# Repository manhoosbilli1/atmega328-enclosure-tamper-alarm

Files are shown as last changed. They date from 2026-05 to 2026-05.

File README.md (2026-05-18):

# Alarming_AC_Enclosure

ATmega328-based AC enclosure tamper/intrusion alarm with PowerPath, voltage monitoring, and dual switching converters

## At a Glance

- **Status**: In progress
- **Board size**: 100 x 60 mm
- **Layers**: 2
- **Components**: 98
- **Key ICs**:
  - U1: 74LVC1G00
  - U2: ATmega328-A
  - U3: LM5158QRTERQ1
  - U4: TPS62933DRLR
  - U5: LTC4412ES6#TRPBF
  - U6: LTC2960CTS8-1#TRMPBF

## Schematic

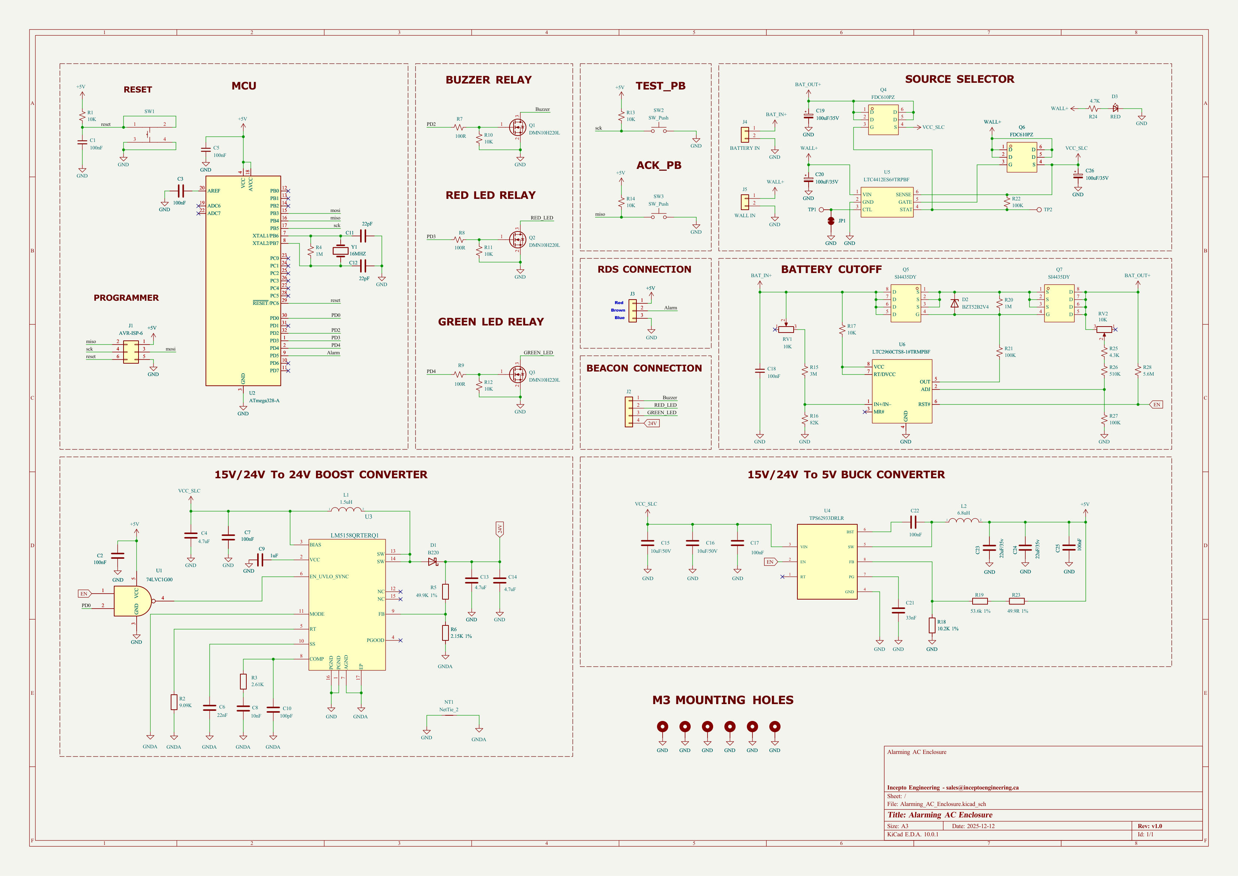
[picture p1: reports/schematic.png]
Schematic


Full PDF: [reports/schematic.pdf](reports/schematic.pdf)

## Component Roles

- **ATmega328-A** - main MCU; reads tamper switches, manages alarm state, drives outputs
- **LTC4412ES6** - low-loss ideal-diode / PowerPath controller; manages source switching between mains-derived rail and backup battery seamlessly
- **LTC2960CTS8-1** - precision voltage monitor / supervisor; trips the alarm if either supply rail dips out of spec
- **LM5158QRTERQ1** - automotive-grade boost converter (LM5158-Q1); steps up battery voltage to feed the alarm load when on backup
- **TPS62933PDRLR** - low-Iq buck converter for the MCU rail (long battery standby)
- **DMN10H220L** - N-channel MOSFET for high-side / load switching
- **FDC610PZ** - P-channel MOSFET (complementary side for OR-ing / load isolation)
- **B220** - Schottky diode for reverse / OR-ing logic
- **BZT52Bxx** - zener diode for clamp / reference
- **1TS005F-2500-5001** - tactile reset/test switch
- **74LVC1G00** - single 2-input NAND gate for combining tamper inputs / debounce logic
- **Crystal** for ATmega clock

> Designed as a self-powered enclosure tamper alarm: stays armed on AC, falls back to battery when AC is cut, alerts when either supply rail is out of spec.

## PCB

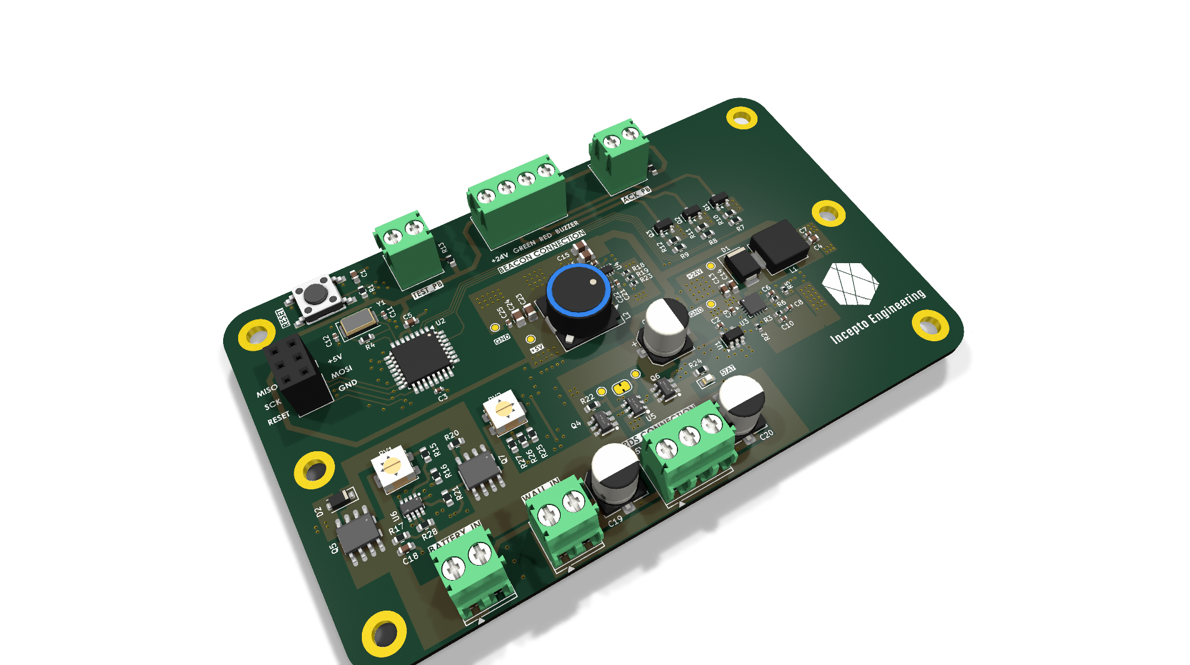
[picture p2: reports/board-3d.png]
3D top


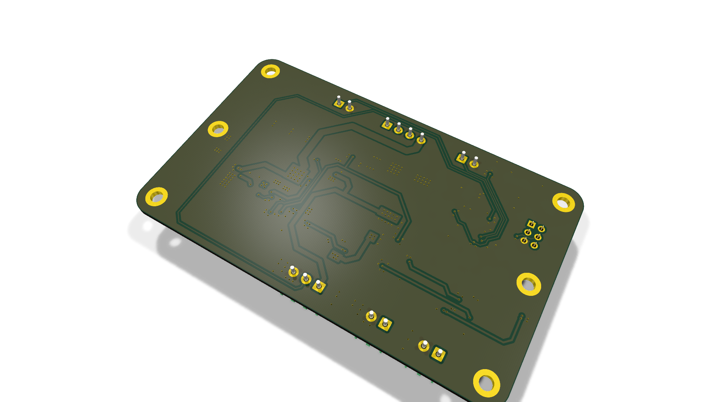
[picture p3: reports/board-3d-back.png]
3D bottom


**Top copper**

PCB top

**Bottom copper**

PCB bottom

## Bill of Materials

| Refs | Value | Footprint | Qty | MPN | LCSC |
|---|---|---|----:|-----|---|
| C1,C5,C18 | 100nF | Capacitor_SMD:C_0603_1608Metric | 3 |  |  |
| C2,C3,C7,C17,C22,C25 | 100nF | Capacitor_SMD:C_0402_1005Metric | 6 |  |  |
| C4,C13,C14 | 4.7uF | Capacitor_SMD:C_0603_1608Metric | 3 |  |  |
| C6 | 22nF | Capacitor_SMD:C_0402_1005Metric | 1 |  |  |
| C8 | 10nF | Capacitor_SMD:C_0402_1005Metric | 1 |  |  |
| C9 | 1uF | Capacitor_SMD:C_0402_1005Metric | 1 |  |  |
| C10 | 100pF | Capacitor_SMD:C_0402_1005Metric | 1 |  |  |
| C11,C12 | 22pF | Capacitor_SMD:C_0402_1005Metric | 2 |  |  |
| C15,C16 | 10uF/50V | Capacitor_SMD:C_0805_2012Metric | 2 |  |  |
| C19,C20,C26 | 100uF/35V | Capacitor_SMD:CP_Elec_6.3x7.7 | 3 |  |  |
| C21 | 33nF | Capacitor_SMD:C_0402_1005Metric | 1 |  |  |
| C23,C24 | 22uF/35v | Capacitor_SMD:C_0805_2012Metric | 2 |  |  |
| D1 | B220 | Diode_SMD:D_SMB | 1 |  |  |
| D2 | BZT52B2V4 | Diode_SMD:D_SOD-123F | 1 |  |  |
| D3 | RED | LED_SMD:LED_0603_1608Metric | 1 |  |  |
| J1 | AVR-ISP-6 | Connector_PinSocket_2.54mm:PinSocket_2x03_P2.54mm_Vertical | 1 |  |  |
| J2 | Conn_01x04 | TerminalBlock_Phoenix:TerminalBlock_Phoenix_PT-1,5-4-3.5-H_1x04_P3.50mm_Horizontal | 1 |  |  |
| J3 | Conn_01x03 | TerminalBlock_Phoenix:TerminalBlock_Phoenix_PT-1,5-3-3.5-H_1x03_P3.50mm_Horizontal | 1 |  |  |
| J4 | BATTERY IN | TerminalBlock_Phoenix:TerminalBlock_Phoenix_PT-1,5-2-3.5-H_1x02_P3.50mm_Horizontal | 1 |  |  |
| J5 | WALL IN | TerminalBlock_Phoenix:TerminalBlock_Phoenix_PT-1,5-2-3.5-H_1x02_P3.50mm_Horizontal | 1 |  |  |
| L1 | 1.5uH | Inductor_SMD:L_Sunlord_MWSA0603S | 1 |  |  |
| L2 | 6.8uH | Inductor_SMD:L_TDK_SLF10165 | 1 |  |  |
| Q1-Q3 | DMN10H220L | Package_TO_SOT_SMD:SOT-23 | 3 |  |  |
| Q4,Q6 | FDC610PZ | FDC610PZ:SOT-23-6_L2.9-W1.6-P0.95-LS2.8-BR | 2 |  |  |
| Q5,Q7 | SI4435DY | SI4435DY:SOP-8_L4.9-W3.9-P1.27-LS6.0-BL | 2 |  |  |
| R1,R10-R14,R17 | 10K | Resistor_SMD:R_0603_1608Metric | 7 |  |  |
| R2 | 9.09K | Resistor_SMD:R_0402_1005Metric | 1 |  |  |
| R3 | 2.61K | Resistor_SMD:R_0402_1005Metric | 1 |  |  |
| R4,R20 | 1M | Resistor_SMD:R_0603_1608Metric | 2 |  |  |
| R5 | 49.9K 1% | Resistor_SMD:R_0402_1005Metric | 1 |  |  |
| R6 | 2.15K 1% | Resistor_SMD:R_0402_1005Metric | 1 |  |  |
| R7-R9 | 100R | Resistor_SMD:R_0603_1608Metric | 3 |  |  |
| R15 | 3M | Resistor_SMD:R_0603_1608Metric | 1 |  |  |
| R16 | 82K | Resistor_SMD:R_0603_1608Metric | 1 |  |  |
| R18 | 10.2K 1% | Resistor_SMD:R_0402_1005Metric | 1 |  |  |
| R19 | 53.6k 1% | Resistor_SMD:R_0402_1005Metric | 1 |  |  |
| R21,R22,R27 | 100K | Resistor_SMD:R_0603_1608Metric | 3 |  |  |
| R23 | 49.9R 1% | Resistor_SMD:R_0402_1005Metric | 1 |  |  |
| R24 | 4.7K | Resistor_SMD:R_0603_1608Metric | 1 |  |  |
| R25 | 4.3K | Resistor_SMD:R_0603_1608Metric | 1 |  |  |
| R26 | 510K | Resistor_SMD:R_0603_1608Metric | 1 |  |  |
| R28 | 5.6M | Resistor_SMD:R_0603_1608Metric | 1 |  |  |
| RV1,RV2 | 10K | Potentiometer_SMD:Potentiometer_Bourns_3314J_Vertical | 2 |  |  |
| SW1 | 1TS005F-2500-5001 | 1TS005F-2500-5001:SW-SMD_4P-L6.0-W6.0-P4.50-LS9.0-H2.5 | 1 |  |  |
| SW2,SW3 | SW_Push | TerminalBlock_Phoenix:TerminalBlock_Phoenix_PT-1,5-2-3.5-H_1x02_P3.50mm_Horizontal | 2 |  |  |
| TP1,TP2 | TestPoint | TestPoint:TestPoint_Pad_D1.5mm | 2 |  |  |
| U1 | 74LVC1G00 | Package_TO_SOT_SMD:SOT-23-5 | 1 |  |  |
| U2 | ATmega328-A | Package_QFP:TQFP-32_7x7mm_P0.8mm | 1 |  |  |
| U3 | LM5158QRTERQ1 | Package_DFN_QFN:WQFN-16-1EP_3x3mm_P0.5mm_EP1.68x1.68mm | 1 |  |  |
| U4 | TPS62933DRLR | Package_TO_SOT_SMD:SOT-583-8 | 1 |  |  |
| U5 | LTC4412ES6#TRPBF | LTC4412ES6#TRPBF:TSOT-23-6_L2.9-W1.6-P0.95-LS2.8-BR | 1 |  |  |
| U6 | LTC2960CTS8-1#TRMPBF | LTC2960CTS8-1#TRMPBF:TSOT-23-8_L2.9-W1.6-P0.65-LS2.8-BL | 1 |  |  |
| Y1 | 16MHZ | Crystal:Crystal_SMD_5032-2Pin_5.0x3.2mm | 1 |  |  |

_53 of 53 line items don't have an LCSC code in the schematic - search [LCSC](https://www.lcsc.com/) or [JLC parts search](https://jlcsearch.tscircuit.com/) by MPN or footprint when sourcing._

## Files

- `Alarming_AC_Enclosure.kicad_pro` - KiCad project
- `Alarming_AC_Enclosure.kicad_sch` - schematic source
- `Alarming_AC_Enclosure.kicad_pcb` - PCB layout source
- `reports/schematic.pdf` - full schematic (printable)
- `reports/bom.csv` - bill of materials
- `reports/pcb-top.svg`, `reports/pcb-bottom.svg` - copper artwork
- `reports/board-stats.json` - KiCad-generated board statistics

---

_Renders and metadata auto-generated by `Backup-KiCadProject.ps1` using KiCad 10.0._

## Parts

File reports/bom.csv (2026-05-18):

Refs | Value | Footprint | Qty | Description | Mfr | MPN | LCSC
C1,C5,C18 | 100nF | Capacitor_SMD:C_0603_1608Metric | 3
C2,C3,C7,C17,C22,C25 | 100nF | Capacitor_SMD:C_0402_1005Metric | 6
C4,C13,C14 | 4.7uF | Capacitor_SMD:C_0603_1608Metric | 3
C6 | 22nF | Capacitor_SMD:C_0402_1005Metric | 1
C8 | 10nF | Capacitor_SMD:C_0402_1005Metric | 1
C9 | 1uF | Capacitor_SMD:C_0402_1005Metric | 1
C10 | 100pF | Capacitor_SMD:C_0402_1005Metric | 1
C11,C12 | 22pF | Capacitor_SMD:C_0402_1005Metric | 2
C15,C16 | 10uF/50V | Capacitor_SMD:C_0805_2012Metric | 2
C19,C20,C26 | 100uF/35V | Capacitor_SMD:CP_Elec_6.3x7.7 | 3 | -55℃~+105℃ 100uF 2000hrs@105℃ 35V 6.3mm 7.7mm ±20% SMD,D6.3xL7.7mm Aluminum Electrolytic Capacitors - SMD ROHS
C21 | 33nF | Capacitor_SMD:C_0402_1005Metric | 1
C23,C24 | 22uF/35v | Capacitor_SMD:C_0805_2012Metric | 2
D1 | B220 | Diode_SMD:D_SMB | 1
D2 | BZT52B2V4 | Diode_SMD:D_SOD-123F | 1 | 500mW Zener Diode, SOD-123F
D3 | RED | LED_SMD:LED_0603_1608Metric | 1 | -40℃~+85℃ 120° 2.4V 20mA 300mcd 40mW 615nm~630nm 645nm Red Water Clear 0603 LED Indication - Discrete ROHS
J1 | AVR-ISP-6 | Connector_PinSocket_2.54mm:PinSocket_2x03_P2.54mm_Vertical | 1 | Generic connector, double row, 02x03, odd/even pin numbering scheme (row 1 odd numbers, row 2 even numbers), script generated (kicad-library-utils/schlib/autogen/connector/)
J2 | Conn_01x04 | TerminalBlock_Phoenix:TerminalBlock_Phoenix_PT-1,5-4-3.5-H_1x04_P3.50mm_Horizontal | 1
J3 | Conn_01x03 | TerminalBlock_Phoenix:TerminalBlock_Phoenix_PT-1,5-3-3.5-H_1x03_P3.50mm_Horizontal | 1
J4 | BATTERY IN | TerminalBlock_Phoenix:TerminalBlock_Phoenix_PT-1,5-2-3.5-H_1x02_P3.50mm_Horizontal | 1 | -40℃~+105℃ 0.5~1.5 1 10A 150V 16~26 1x2P 2 2P 3.5mm Green M2 Through Hole Plugin,P=3.5mm Screw Terminal Blocks ROHS
J5 | WALL IN | TerminalBlock_Phoenix:TerminalBlock_Phoenix_PT-1,5-2-3.5-H_1x02_P3.50mm_Horizontal | 1 | -40℃~+105℃ 0.5~1.5 1 10A 150V 16~26 1x2P 2 2P 3.5mm Green M2 Through Hole Plugin,P=3.5mm Screw Terminal Blocks ROHS
L1 | 1.5uH | Inductor_SMD:L_Sunlord_MWSA0603S | 1
L2 | 6.8uH | Inductor_SMD:L_TDK_SLF10165 | 1
Q1-Q3 | DMN10H220L | Package_TO_SOT_SMD:SOT-23 | 3
Q4,Q6 | FDC610PZ | FDC610PZ:SOT-23-6_L2.9-W1.6-P0.95-LS2.8-BR | 2 | -55℃~+150℃ 1 P-Channel 1.005nF 1.6W 190pF 195pF 24nC@10V 30V 3V@250uA 4.9A 75mΩ@4.5V P-Channel SuperSOT-6 MOSFETs ROHS
Q5,Q7 | SI4435DY | SI4435DY:SOP-8_L4.9-W3.9-P1.27-LS6.0-BL | 2 | -55℃~+150℃ 1.2nF@15V 12A 150pF 1V 25nC 30V 3W 9.5mΩ@10V SOP-8 MOSFETs ROHS
R1,R10-R14,R17 | 10K | Resistor_SMD:R_0603_1608Metric | 7
R2 | 9.09K | Resistor_SMD:R_0402_1005Metric | 1
R3 | 2.61K | Resistor_SMD:R_0402_1005Metric | 1
R4,R20 | 1M | Resistor_SMD:R_0603_1608Metric | 2
R5 | 49.9K 1% | Resistor_SMD:R_0402_1005Metric | 1
R6 | 2.15K 1% | Resistor_SMD:R_0402_1005Metric | 1
R7-R9 | 100R | Resistor_SMD:R_0603_1608Metric | 3
R15 | 3M | Resistor_SMD:R_0603_1608Metric | 1
R16 | 82K | Resistor_SMD:R_0603_1608Metric | 1
R18 | 10.2K 1% | Resistor_SMD:R_0402_1005Metric | 1
R19 | 53.6k 1% | Resistor_SMD:R_0402_1005Metric | 1
R21,R22,R27 | 100K | Resistor_SMD:R_0603_1608Metric | 3
R23 | 49.9R 1% | Resistor_SMD:R_0402_1005Metric | 1
R24 | 4.7K | Resistor_SMD:R_0603_1608Metric | 1
R25 | 4.3K | Resistor_SMD:R_0603_1608Metric | 1
R26 | 510K | Resistor_SMD:R_0603_1608Metric | 1
R28 | 5.6M | Resistor_SMD:R_0603_1608Metric | 1
RV1,RV2 | 10K | Potentiometer_SMD:Potentiometer_Bourns_3314J_Vertical | 2 | 1 10kΩ 250mW ±100ppm/℃ ±20% SMD,4.5x4.5mm Potentiometers, Variable Resistors ROHS
SW1 | 1TS005F-2500-5001 | 1TS005F-2500-5001:SW-SMD_4P-L6.0-W6.0-P4.50-LS9.0-H2.5 | 1 | Circuit:SPST Actuator Style:Round Button Operating Force:2.5N Mounting Type:Surface Mount,Vertical Length:6mm Width:6mm Switch Height:5mm with Bracket:Without Bracket Contact Current:50mA Voltage Rating:12V Actuator/Cap Color:Black With Lamp:No Terminatio
SW2,SW3 | SW_Push | TerminalBlock_Phoenix:TerminalBlock_Phoenix_PT-1,5-2-3.5-H_1x02_P3.50mm_Horizontal | 2
TP1,TP2 | TestPoint | TestPoint:TestPoint_Pad_D1.5mm | 2 | test point
U1 | 74LVC1G00 | Package_TO_SOT_SMD:SOT-23-5 | 1
U2 | ATmega328-A | Package_QFP:TQFP-32_7x7mm_P0.8mm | 1
U3 | LM5158QRTERQ1 | Package_DFN_QFN:WQFN-16-1EP_3x3mm_P0.5mm_EP1.68x1.68mm | 1
U4 | TPS62933DRLR | Package_TO_SOT_SMD:SOT-583-8 | 1 | -40℃~+150℃@(TJ) 1 12uA 2.2MHz 3.8V~30V 3A 800mV~22V Adjustable Buck Buck Built-In Yes SOT-583 DC-DC Converters ROHS
U5 | LTC4412ES6#TRPBF | LTC4412ES6#TRPBF:TSOT-23-6_L2.9-W1.6-P0.95-LS2.8-BR | 1 | -40℃~+85℃ 1 110us 11uA 13us 2.5V~28V 350mV 635mV MOSFET TSOT-23-6 Gate Drivers ROHS
U6 | LTC2960CTS8-1#TRMPBF | LTC2960CTS8-1#TRMPBF:TSOT-23-8_L2.9-W1.6-P0.65-LS2.8-BL | 1 | 0℃~+70℃@(Tj) 15ms 2 2.5V~36V 400mV 850nA Active Low Open Drain Voltage Monitor Yes TSOT-23-8 Supervisor and Reset ICs ROHS
Y1 | 16MHZ | Crystal:Crystal_SMD_5032-2Pin_5.0x3.2mm | 1

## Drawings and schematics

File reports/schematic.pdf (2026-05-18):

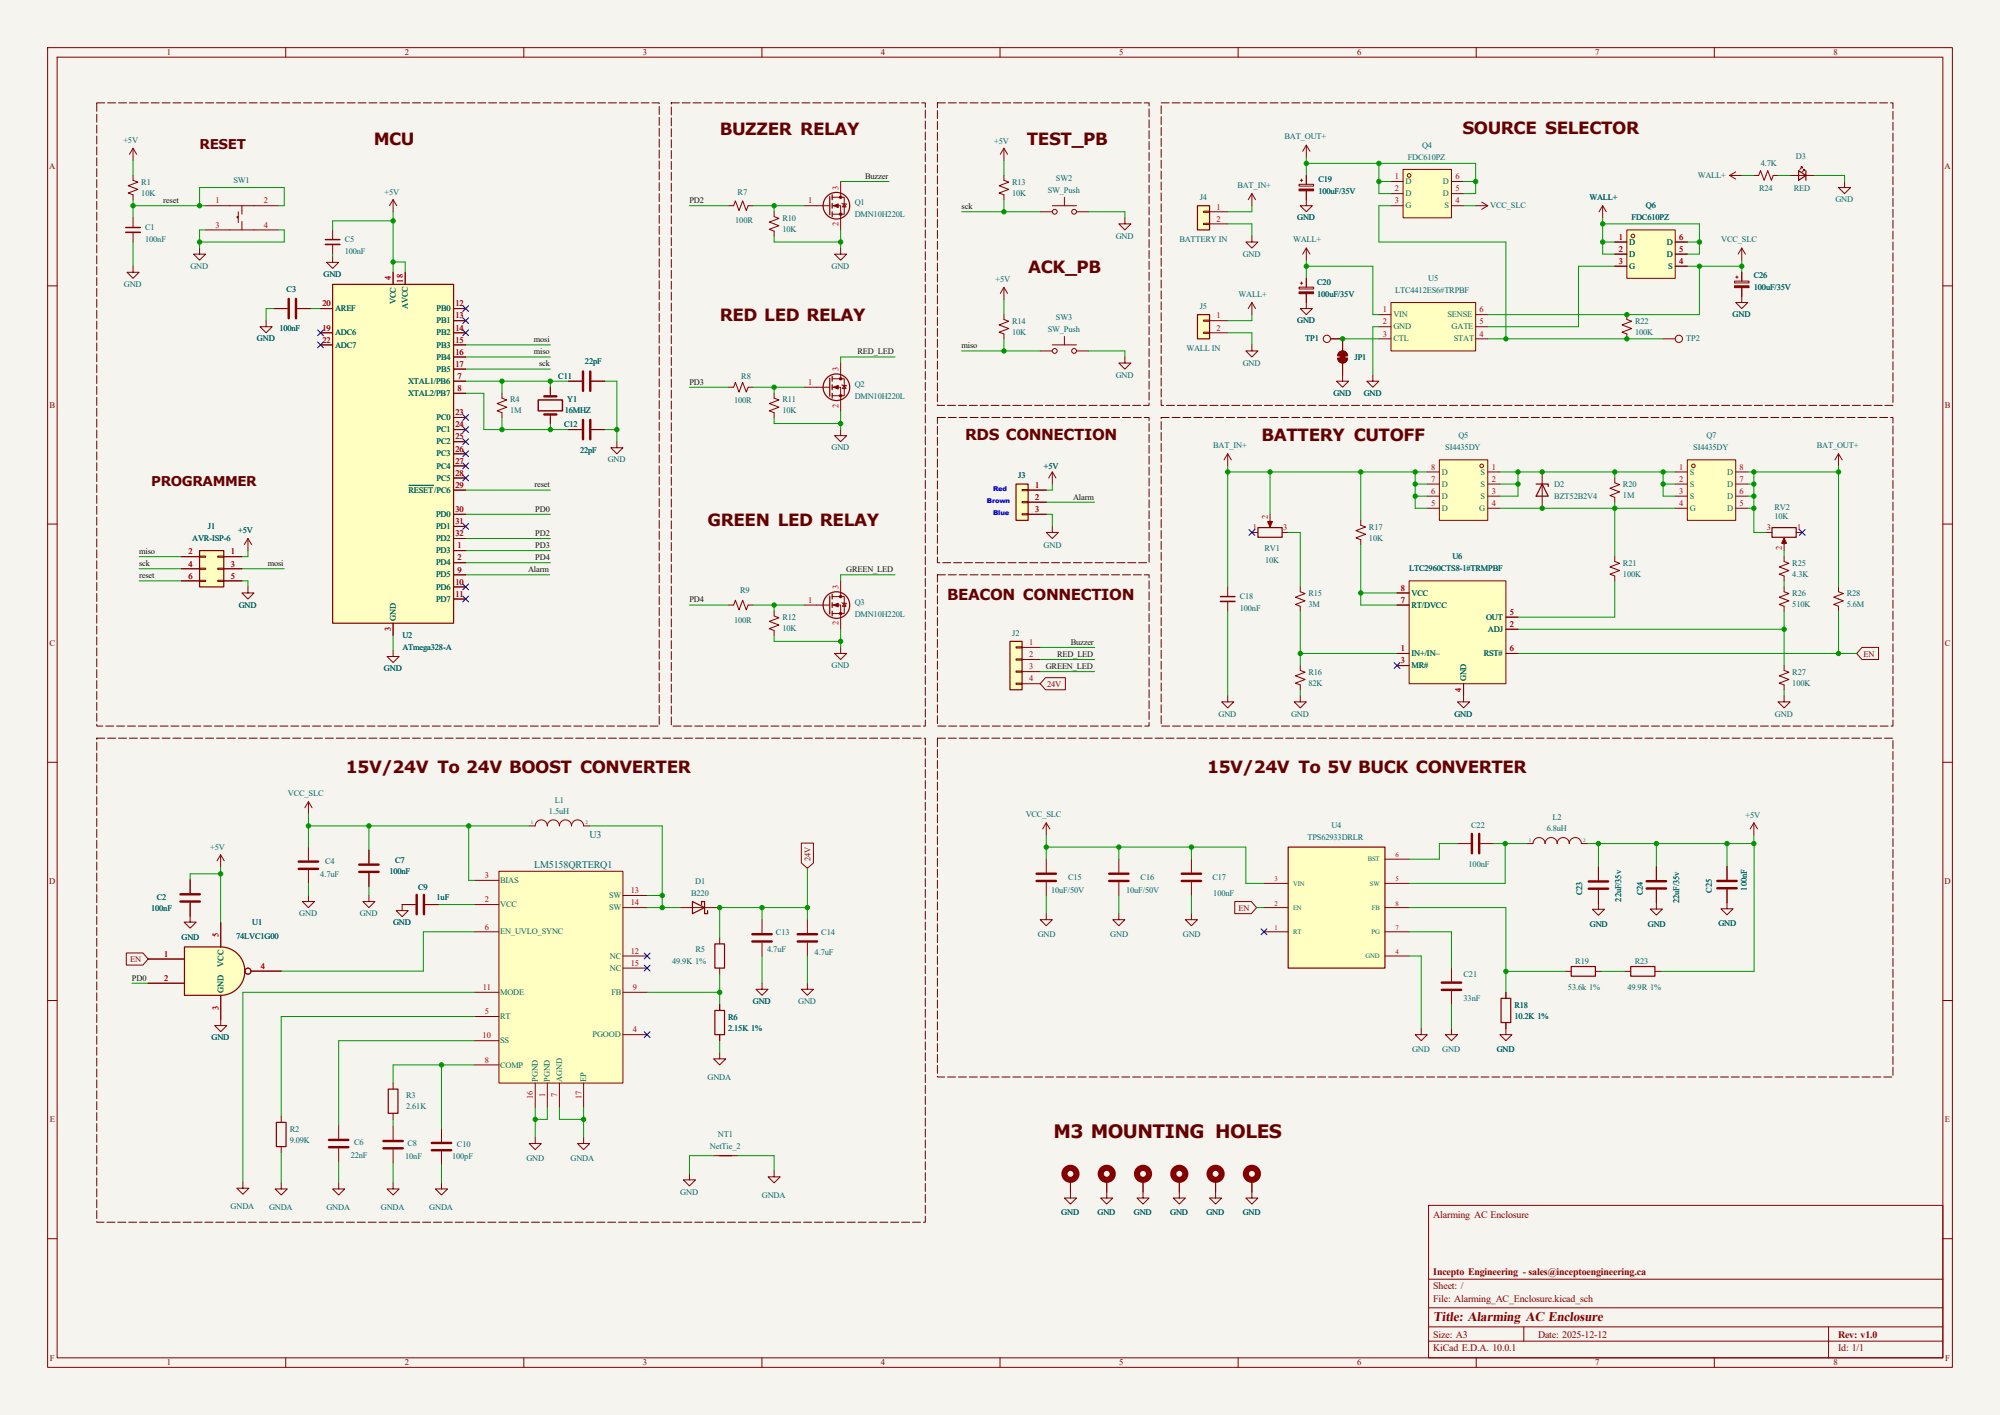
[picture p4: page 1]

4 OUT 5 RST# 6 RT/DVCC 7 VCC 8 GND

4 OUT 5 RST# 6 RT/DVCC 7 VCC 8 U6 LTC2960CTS8-1#TRMPBF GND GND

7 COMP 8 FB 9 SS 10 MODE 11 NC 12 SW 13 SW 14 NC 15 PGND 16 EP 17 U3 LM5158QRTERQ1 C9

1 VCC 2 BIAS 3 PGOOD 4 RT 5 EN_UVLO_SYNC 6 AGND

File: Alarming_AC_Enclosure.kicad_sch Sheet: / Incepto Engineering - sales@inceptoengineering.ca

Id: 1/1 Title: Alarming AC Enclosure

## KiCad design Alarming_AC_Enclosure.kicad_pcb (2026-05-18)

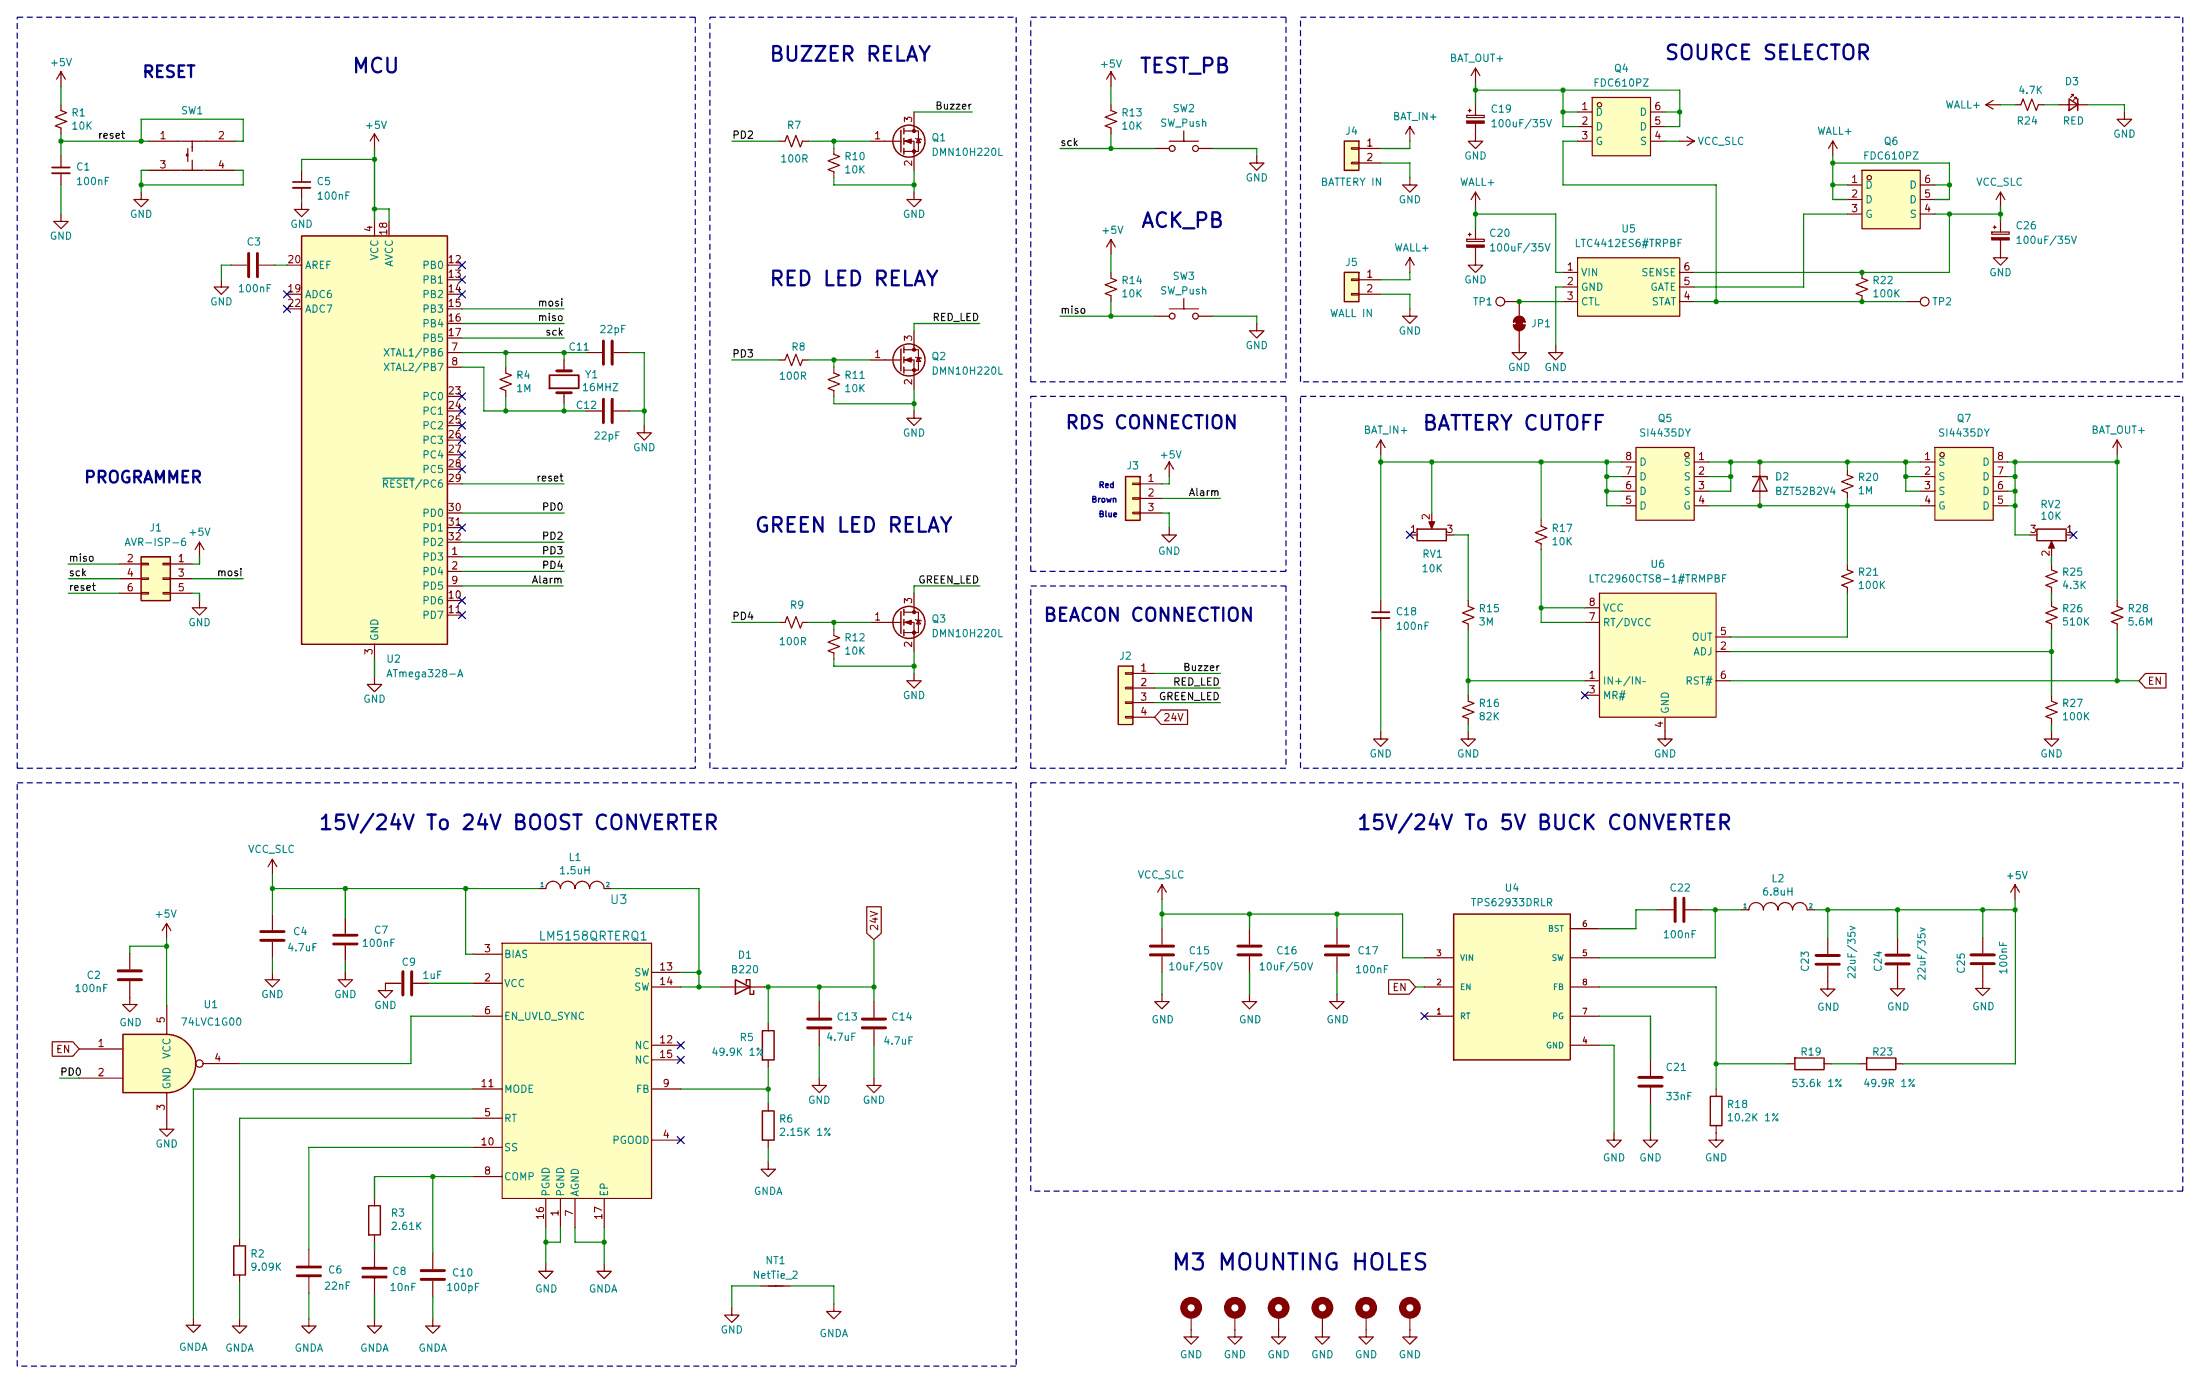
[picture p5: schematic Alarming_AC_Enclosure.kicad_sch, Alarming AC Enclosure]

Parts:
C1, C5, C18: 100nF; C_0603_1608Metric; JLCPCB Part # C14663
C2, C3, C7, C17, C22, C25: 100nF; C_0402_1005Metric; JLCPCB Part # C307331
C4, C13, C14: 4.7uF; C_0603_1608Metric; JLCPCB Part # C69335
C6: 22nF; C_0402_1005Metric; JLCPCB Part # C1532
C8: 10nF; C_0402_1005Metric; JLCPCB Part # C15195
C9: 1uF; C_0402_1005Metric; JLCPCB Part # C52923
C10: 100pF; C_0402_1005Metric; JLCPCB Part # C1546
C11, C12: 22pF; C_0402_1005Metric; JLCPCB Part # C1555
C15, C16: 10uF/50V; C_0805_2012Metric; JLCPCB Part # C440198
C19, C20, C26: 100uF/35V; CP_Elec_6.3x7.7; JLCPCB Part # C3339
C21: 33nF; C_0402_1005Metric; JLCPCB Part # C106862
C23, C24: 22uF/35v; C_0805_2012Metric; JLCPCB Part # C338080
D1: B220; D_SMB; JLCPCB Part # C110480
D2: BZT52B2V4; D_SOD-123F; JLCPCB Part # C3019930
D3: RED; LED_0603_1608Metric; JLCPCB Part # C2286
H1, H2, H3, H4, H5, H6: MountingHole; MountingHole_3.2mm_M3_DIN965_Pad
J1: AVR-ISP-6; PinSocket_2x03_P2.54mm_Vertical; JLCPCB Part # C7501274
J2: Conn_01x04; TerminalBlock_Phoenix_PT-1,5-4-3.5-H_1x04_P3.50mm_Horizontal; JLCPCB Part # C2757925
J3: Conn_01x03; TerminalBlock_Phoenix_PT-1,5-3-3.5-H_1x03_P3.50mm_Horizontal; JLCPCB Part # C466971
J4: BATTERY IN; TerminalBlock_Phoenix_PT-1,5-2-3.5-H_1x02_P3.50mm_Horizontal; JLCPCB Part # C415432
J5: WALL IN; TerminalBlock_Phoenix_PT-1,5-2-3.5-H_1x02_P3.50mm_Horizontal; JLCPCB Part # C415432
JP1: SolderJumper_2_Bridged; SolderJumper-2_P1.3mm_Bridged_RoundedPad1.0x1.5mm
L1: 1.5uH; L_Sunlord_MWSA0603S; JLCPCB Part # C167217
L2: 6.8uH; L_TDK_SLF10165; JLCPCB Part # C138669
NT1: NetTie_2; NetTie-2_SMD_Pad2.0mm
Q1, Q2, Q3: DMN10H220L; SOT-23; JLCPCB Part # C5122013
Q4, Q6: FDC610PZ; SOT-23-6_L2.9-W1.6-P0.95-LS2.8-BR; JLCPCB Part # C241761
Q5, Q7: SI4435DY; SOP-8_L4.9-W3.9-P1.27-LS6.0-BL; JLCPCB Part # C4355022
R1, R10, R11, R12, R13, R14, R17: 10K; R_0603_1608Metric; JLCPCB Part # C25804
R2: 9.09K; R_0402_1005Metric; JLCPCB Part # C11549
R3: 2.61K; R_0402_1005Metric; JLCPCB Part # C34906
R4, R20: 1M; R_0603_1608Metric; JLCPCB Part # C22935
R5: 49.9K 1%; R_0402_1005Metric; JLCPCB Part # C25897
R6: 2.15K 1%; R_0402_1005Metric; JLCPCB Part # C25878
R7, R8, R9: 100R; R_0603_1608Metric; JLCPCB Part # C22775
R15: 3M; R_0603_1608Metric; JLCPCB Part # C23156
R16: 82K; R_0603_1608Metric; JLCPCB Part # C23254
R18: 10.2K 1%; R_0402_1005Metric; JLCPCB Part # C11660
R19: 53.6k 1%; R_0402_1005Metric; JLCPCB Part # C53398
R21, R22, R27: 100K; R_0603_1608Metric; JLCPCB Part # C25803
R23: 49.9R 1%; R_0402_1005Metric; JLCPCB Part # C25120
R24: 4.7K; R_0603_1608Metric; JLCPCB Part # C23162
R25: 4.3K; R_0603_1608Metric; JLCPCB Part # C23159
R26: 510K; R_0603_1608Metric; JLCPCB Part # C23192
R28: 5.6M; R_0603_1608Metric; JLCPCB Part # C23190
RV1, RV2: 10K; Potentiometer_Bourns_3314J_Vertical; JLCPCB Part # C36376
SW1: 1TS005F-2500-5001; SW-SMD_4P-L6.0-W6.0-P4.50-LS9.0-H2.5; JLCPCB Part # C255812
SW2, SW3: SW_Push; TerminalBlock_Phoenix_PT-1,5-2-3.5-H_1x02_P3.50mm_Horizontal; JLCPCB Part # C415432
TP1, TP2: TestPoint; TestPoint_Pad_D1.5mm
U1: 74LVC1G00; SOT-23-5; JLCPCB Part # C434066
U2: ATmega328-A; TQFP-32_7x7mm_P0.8mm; JLCPCB Part # C14877
U3: LM5158QRTERQ1; WQFN-16-1EP_3x3mm_P0.5mm_EP1.68x1.68mm; JLCPCB Part # C3188431
U4: TPS62933DRLR; SOT-583-8; JLCPCB Part # C3200405
U5: LTC4412ES6#TRPBF; TSOT-23-6_L2.9-W1.6-P0.95-LS2.8-BR; JLCPCB Part # C514442
U6: LTC2960CTS8-1#TRMPBF; TSOT-23-8_L2.9-W1.6-P0.65-LS2.8-BL; JLCPCB Part # C683822
Y1: 16MHZ; Crystal_SMD_5032-2Pin_5.0x3.2mm; JLCPCB Part # C251590

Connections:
24V: C13.1, C14.1, D1.1 (K), J2.4, R5.1; also elsewhere on the board
+5V: C2.2, C5.1, C23.1, C24.1, C25.2, J1.1, J3.1, L2.2, R1.1, R13.1, R14.1, R23.1, U1.5 (VCC), U2.4 (VCC), U2.6 (VCC), U2.18 (AVCC); also elsewhere on the board
/Alarm: J3.2, U2.9 (PD5)
/Buzzer: J2.1, Q1.3 (D)
/GREEN_LED: J2.3, Q3.3 (D)
/PD0: U1.2, U2.30 (PD0)
/PD2: R7.1, U2.32 (PD2)
/PD3: R8.1, U2.1 (PD3)
/PD4: R9.1, U2.2 (PD4)
/RED_LED: J2.2, Q2.3 (D)
/miso: J1.2, R14.2, SW3.1, U2.16 (PB4)
/mosi: J1.3, U2.15 (PB3)
/reset: C1.1, J1.6, R1.2, SW1.1, SW1.2, U2.29 (~RESET/PC6)
/sck: J1.4, R13.2, SW2.1, U2.17 (PB5)
BAT_IN+: C18.1, J4.1, Q5.5 (D), Q5.6 (D), Q5.7 (D), Q5.8 (D), R17.1, RV1.2
BAT_OUT+: C19.1, Q4.1 (D), Q4.2 (D), Q4.5 (D), Q4.6 (D), Q7.5 (D), Q7.6 (D), Q7.7 (D), Q7.8 (D), R28.1, RV2.3
EN: R28.2, U1.1, U4.2 (EN), U6.6 (RST#)
GND: C1.2, C2.1, C3.2, C4.2, C5.2, C7.1, C9.1, C11.2, C12.2, C13.2, C14.2, C15.2, C16.2, C17.1, C18.2, C19.2, C20.2, C21.2, C23.2, C24.2, C25.1, C26.2, D3.1 (K), H1.1, H2.1, H3.1, H4.1, H5.1, H6.1, J1.5, J3.3, J4.2, J5.2, JP1.1 (A), NT1.1, Q1.2 (S), Q2.2 (S), Q3.2 (S), R10.2, R11.2, R12.2, R16.2, R18.2, R27.2, SW1.3, SW1.4, SW2.2, SW3.2, U1.3 (GND), U2.3 (GND), U2.5 (GND), U2.21 (GND), U3.1 (PGND), U3.16 (PGND), U4.4 (GND), U5.2 (GND), U6.4 (GND); also elsewhere on the board
GNDA: C6.2, C8.2, C10.2, NT1.2, R2.2, R6.2, U3.7 (AGND), U3.11 (MODE), U3.17 (EP)
unnamed: C8.1, R3.2
unnamed: D1.2 (A), L1.2, U3.13 (SW), U3.14 (SW)
unnamed: D2.2 (A), Q5.4 (G), Q7.4 (G), R20.2, R21.1
unnamed: D2.1 (K), Q5.1 (S), Q5.2 (S), Q5.3 (S), Q7.1 (S), Q7.2 (S), Q7.3 (S), R20.1
unnamed: D3.2 (A), R24.2
unnamed: JP1.2 (B), TP1.1, U5.3 (CTL)
unnamed: Q1.1 (G), R7.2, R10.1
unnamed: Q2.1 (G), R8.2, R11.1
unnamed: Q3.1 (G), R9.2, R12.1
unnamed: Q4.3 (G), R22.2, TP2.1, U5.4 (STAT)
unnamed: Q6.3 (G), U5.5 (GATE)
unnamed: R15.1, RV1.3
unnamed: R19.1, R23.2
unnamed: R25.1, RV2.2
unnamed: R25.2, R26.1
unnamed: C3.1, U2.20 (AREF)
unnamed: C11.1, R4.1, U2.7 (XTAL1/PB6), Y1.2
unnamed: C12.1, R4.2, U2.8 (XTAL2/PB7), Y1.1
unnamed: C10.1, R3.1, U3.8 (COMP)
unnamed: U1.4, U3.6 (EN_UVLO_SYNC)
unnamed: R5.2, R6.1, U3.9 (FB)
unnamed: R2.1, U3.5 (RT)
unnamed: C6.1, U3.10 (SS)
unnamed: C9.2, U3.2 (VCC)
unnamed: C22.1, U4.6 (BST)
unnamed: R18.1, R19.2, U4.8 (FB)
unnamed: C21.1, U4.7 (PG)
unnamed: C22.2, L2.1, U4.5 (SW)
unnamed: R26.2, R27.1, U6.2 (ADJ)
unnamed: R15.2, R16.1, U6.1 (IN+/IN–)
unnamed: R21.2, U6.5 (OUT)
unnamed: R17.2, U6.7 (RT/DVCC), U6.8 (VCC)
VCC_SLC: C4.1, C7.2, C15.1, C16.1, C17.2, C26.1, L1.1, Q4.4 (S), Q6.4 (S), R22.1, U3.3 (BIAS), U4.3 (VIN), U5.6 (SENSE)
WALL+: C20.1, J5.1, Q6.1 (D), Q6.2 (D), Q6.5 (D), Q6.6 (D), R24.1, U5.1 (VIN)

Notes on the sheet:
Red
Blue
15V/24V To 24V BOOST CONVERTER
RED LED RELAY
TEST_PB
15V/24V To 5V BUCK CONVERTER
RDS CONNECTION
ACK_PB
Brown
RESET
BATTERY CUTOFF
MCU
SOURCE SELECTOR
M3 MOUNTING HOLES
BEACON CONNECTION
PROGRAMMER
BUZZER RELAY
GREEN LED RELAY

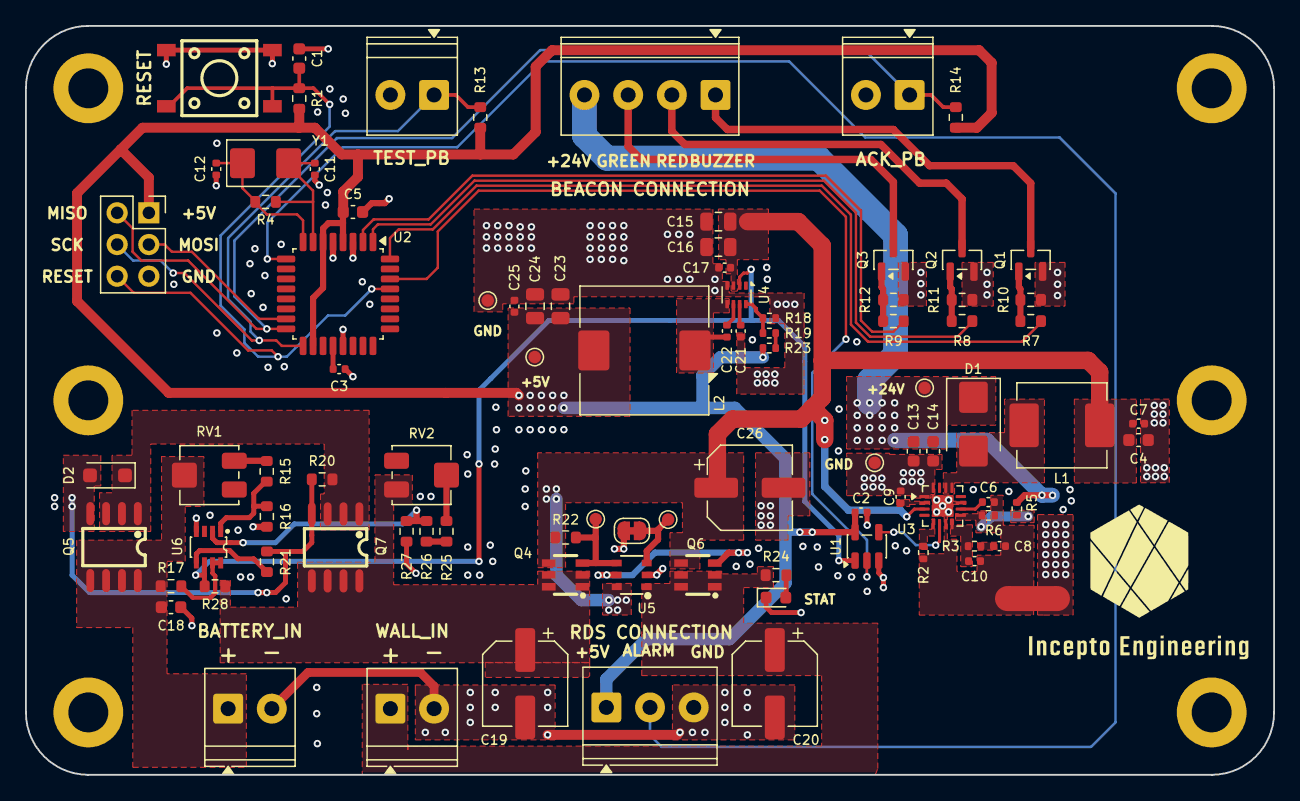
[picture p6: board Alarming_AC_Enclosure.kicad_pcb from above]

Board: 2 copper layers, 100.0 x 60.0 mm, 97 parts (0 on the bottom side), 53 nets.

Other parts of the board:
TP3, TP4, TP5, TP6: TestPoint; TestPoint_Pad_D1.0mm

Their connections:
24V: TP3.1; also elsewhere on the board
+5V: TP5.1; also elsewhere on the board
GND: TP4.1, TP6.1; also elsewhere on the board

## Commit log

2026-05-18 Initial backup: schematic, PCB, renders, BOM
    [Alarming_AC_Enclosure.kicad_pcb, Alarming_AC_Enclosure.kicad_sch, bom.csv]
2026-05-18 Enrich README: schematic PNG, component roles, BOM table
